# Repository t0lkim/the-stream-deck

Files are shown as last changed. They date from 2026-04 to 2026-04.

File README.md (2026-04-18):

# TheStreamDeck

A Raspberry Pi-based unified streaming audio appliance. One device, one amp input, instant source switching, album art on screen, and physical analogue VU meters.

## Sources

- Tidal HiFi Plus
- Plexamp (local library)
- BBC 6 Music
- Internet radio

## Features

- Touchscreen display with album artwork and transport controls
- Physical analogue VU meters showing real-time audio levels
- Instant source switching — tap to change from Tidal to BBC radio without touching the amplifier
- Single amp input eliminates multi-device cable management

## Platform

Raspberry Pi

## License

MIT

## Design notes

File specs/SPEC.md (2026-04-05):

# TheStreamDeck — Unified Streaming Audio Appliance

**Version:** 0.2.0 (Design Spec)  
**Author:** Mike & Maia  
**Date:** 2026-04-04  
**Status:** Draft  

---

## 1. Overview

A Raspberry Pi 4-based appliance that consolidates BBC 6 Music, Tidal HiFi Plus, Plexamp, and internet radio into a single device with a 13.3" touchscreen, physical source-selection buttons, real-time VU meter visualisation, and S/PDIF digital output to a NAD C 3xx integrated amplifier.

One device. One amp input. Instant switching. Album art on screen.

---

## 2. Hardware Architecture

### 2.1 Core Components

| Component | Selection | Rationale |
|---|---|---|
| **SBC** | Raspberry Pi 4 Model B (4GB) | Already owned. Quad A72 @ 1.5GHz, VideoCore VI GPU. |
| **Transport HAT** | HiFiBerry Digi2 Pro | S/PDIF output (optical + coax), dual oscillator for low jitter, 192kHz/24-bit. NOT a DAC — pure digital transport. |
| **Display** | Waveshare 13.3" HDMI LCD (H) V2 with Case | 1920x1080 IPS, HDMI + USB touch (no GPIO conflict), 10-point capacitive, toughened glass, built-in speaker, tilt stand. ~$160-190. |
| **Amplifier** | NAD C 3xx (existing) | Optical digital input, Cirrus Logic internal DAC. Handles all D/A conversion. |
| **VU Meter DAC** | MCP4922 (DIP-16) | Dual 12-bit SPI DAC. Drives L/R analogue panel meters. Zero jitter, 4096 steps. SPI0 (GPIO 8/10/11) — no HiFiBerry conflict. ~$3-4. |
| **VU Panel Meters** | 2x 85mm analogue VU meters with backlight | Moving-coil needle meters, 200uA FSD. Driven by MCP4922 via series resistor (15k + 5k trim pot per channel). ~$8-40/pair depending on quality tier. |
| **Storage** | 64GB A2 microSD | Fast random I/O for OS + applications. |
| **Network** | Ethernet (wired) | Reliability for streaming. Wi-Fi available as fallback. |

### 2.2 Audio Signal Path

```
Streaming Source (Tidal / Plexamp / MPD)
    |
    v
PipeWire (audio server / multiplexer)
    |
    +---> HiFiBerry Digi2 Pro (I2S → S/PDIF framing)
    |         |
    |         +---> TOSLINK optical cable
    |                   |
    |                   v
    |              NAD C 3xx optical input
    |                   |
    |                   v
    |              NAD internal DAC (Cirrus Logic, D/A conversion)
    |                   |
    |                   v
    |              NAD amplifier stage → Speakers
    |
    +---> PipeWire monitor source (audio tap for visualisation)
              |
              v
         VU Meter / Spectrum Analyser (cpal + RustFFT → display)
```

**Why Digi HAT, not DAC HAT:**
- The Pi stays purely digital — zero analogue stages on the Pi side
- The NAD's Cirrus Logic DAC is purpose-built with dedicated power regulation and shielding — objectively superior to any ~$30 Pi HAT DAC
- Using a DAC HAT to feed the NAD's analogue input = unnecessary double conversion (digital → HAT DAC → analogue → NAD → amp)
- TOSLINK optical provides galvanic isolation, eliminating ground loop hum from the Pi's switching PSU
- Full 24-bit/192kHz support end-to-end

### 2.3 Physical Controls

Source switching buttons connected via GPIO (pins not used by Digi HAT — HDMI display uses no GPIO):

| Button | Function | GPIO Pin (suggested) |
|---|---|---|
| 1 | BBC 6 Music | GPIO 17 |
| 2 | Tidal | GPIO 27 |
| 3 | Plexamp | GPIO 22 |
| 4 | Radio (cycle presets) | GPIO 23 |
| 5 | Play/Pause | GPIO 24 |
| 6 | Volume +/- (rotary encoder) | GPIO 5/6 |

The touchscreen also provides full source selection and transport controls.

### 2.4 GPIO Pin Allocation

| Pin Range | Used By |
|---|---|
| GPIO 18, 19, 20, 21 | HiFiBerry Digi2 Pro (I2S: BCK, LRCK, DIN, DOUT) |
| GPIO 4 | HiFiBerry Digi2 Pro (clock select) |
| GPIO 8 (SPI0 CE0) | MCP4922 DAC chip select |
| GPIO 10 (SPI0 MOSI) | MCP4922 DAC data in |
| GPIO 11 (SPI0 SCLK) | MCP4922 DAC clock |
| GPIO 2-3 (I2C) | Available |
| GPIO 17, 22-24, 27 | Physical buttons |
| GPIO 5, 6 | Rotary encoder (volume) |

Display connects via HDMI (video) + USB (touch) — zero GPIO usage. No conflicts between display, Digi HAT, DAC, and buttons.

### 2.5 Analogue VU Meter Subsystem

Physical needle VU meters driven digitally from the audio analysis pipeline via SPI DAC.

**Signal chain:**
```
PipeWire monitor tap → RMS per channel (Rust)
    → VU ballistics filter (300ms IIR)
    → MCP4922 SPI write (12-bit, dual channel)
    → Series resistor (15k + 5k trim pot)
    → 85mm analogue panel meter (200uA FSD)
```

**Wiring:**
```
Pi 3.3V ──── MCP4922 VDD, VRefA, VRefB, SHDN
Pi GND  ──── MCP4922 VSS, LDAC
Pi GPIO8 ─── MCP4922 CS
Pi GPIO10 ── MCP4922 SDI
Pi GPIO11 ── MCP4922 SCK

MCP4922 VOutA ──[15k + 5k trim]── VU Left+  ── VU Left-  ── GND
MCP4922 VOutB ──[15k + 5k trim]── VU Right+ ── VU Right- ── GND
```

**Why not PWM?** Hardware PWM on GPIO 18 conflicts with HiFiBerry PCM_CLK. Software PWM produces visible needle jitter (~13 usable steps). The MCP4922 gives 4096 steps with zero jitter — proven superior in head-to-head testing (Hackaday.io reference project).

**Power:** Both meters draw ~0.4mA total from the Pi's 3.3V rail. Negligible.

**Ballistics:** Implement a VU-standard IIR filter in software (300ms time constant, 1-1.5% overshoot). Cheap meters need software damping due to poor mechanical damping. Quality meters (Flash Star, Hoyt) can rely on their own mechanical inertia with only a gentle 50ms software smoothing pass.

**Meter quality tiers:**

| Tier | Source | Price/pair | Damping | Notes |
|---|---|---|---|---|
| Budget | AliExpress "85mm VU meter" | $8-15 | Poor — needs software compensation | Adequate for decorative/indicative use |
| Mid-range | Flash Star / Sifam | $30-40 each | Good — proper VU behaviour | Recommended for this build |
| Professional | Hoyt AL19R/AL20 | $50-150 each | Excellent — ANSI-standard | Buy-once quality |

---

## 3. Software Architecture

### 3.1 OS Layer

| Component | Choice | Notes |
|---|---|---|
| **OS** | Raspberry Pi OS Lite 64-bit (Bookworm) | Minimal, ARM64, PipeWire default |
| **Audio Server** | PipeWire | Default on Bookworm. Multiplexes all sources. Monitor sources for visualisation. |
| **Container Runtime** | Podman (rootless) | For Tidal Connect. No Docker daemon. |
| **Init** | systemd | User services for Plexamp, system services for MPD |

### 3.2 Audio Sources

#### BBC 6 Music (and other BBC/internet radio)
- **Player:** MPD (Music Player Daemon)
- **Protocol:** HLS (AAC-LC)
- **Quality:** 320kbps AAC (UK), 96kbps (worldwide)
- **Stream URL:** `http://lstn.lv/bbc.m3u8?station=bbc_6music&bitrate=320000`
- **Config:** MPD playlist entries for each station
- **Switching:** MPD client commands (`mpc play`, `mpc stop`)
- **Metadata:** MPD provides ICY metadata (artist/title) from stream

#### Tidal HiFi Plus
- **Player:** GioF71/tidal-connect (Podman container)
- **Protocol:** Tidal Connect (proprietary, runs inside container)
- **Quality:** Lossless FLAC (16/44.1 or 24/96 depending on source)
- **Auth:** OAuth via Tidal mobile app (cast to this device)
- **Control model:** Cast-based — control from Tidal app on phone/tablet, Pi is the renderer
- **Metadata API:** OpenTidal (TypeScript) or rstidal (Rust) for album art, track info
- **Container config:**
  ```bash
  podman run -d --name tidal-connect \
    --device /dev/snd \
    -e FRIENDLY_NAME="StreamDeck" \
    -e FORCE_PLAYER_BACKEND="PipeWire" \
    giof71/tidal-connect:latest
  ```

#### Plexamp (Local Plex Library)
- **Player:** Plexamp headless (Node.js 20)
- **Requirement:** Plex Pass (mandatory)
- **Setup:** systemd user service via odinb/bash-plexamp-installer
- **Control model:** Cast-based — control from any Plexamp client on network
- **Web UI:** `http://localhost:32500` — can display in Chromium kiosk on touchscreen
- **Quality:** Depends on Plex library encoding (FLAC preferred)
- **Metadata:** Plex API provides full album art, artist info, lyrics

#### Internet Radio (Generic)
- **Player:** MPD
- **Protocol:** HLS, Shoutcast/Icecast (varies per station)
- **Config:** MPD playlist with station URLs
- **Presets:** Configurable list of favourite stations

### 3.3 Source Switching Architecture

```
                    ┌─────────────────────┐
                    │   Source Controller  │
                    │   (Rust daemon)      │
                    └─────────┬───────────┘
                              │
              ┌───────────────┼───────────────┐
              │               │               │
              v               v               v
        ┌──────────┐   ┌──────────┐   ┌──────────┐
        │   MPD    │   │  Tidal   │   │ Plexamp  │
        │ (radio)  │   │ Connect  │   │(headless)│
        └────┬─────┘   └────┬─────┘   └────┬─��───┘
             │               │               │
             └───────────────┼───────────────┘
                             │
                             v
                    ┌─────────────────────┐
                    │     PipeWire        │
                    │  (session manager)  │
                    └─────────┬───────────┘
                              │
                    ┌─────────┴─────────┐
                    │                   │
                    v                   v
           ┌──────────────┐   ┌──────────────┐
           │ Digi2 Pro    │   │ Monitor Src  │
           │ (S/PDIF out) │   │ (VU meter)   │
           └──────────────┘   └──────────────┘
```

**Source Controller** is a custom Rust daemon that:
1. Listens for GPIO button presses and touchscreen source-select events
2. Mutes/stops the current source (e.g., `mpc stop` for MPD)
3. Activates the new source
4. Updates the UI to reflect active source
5. PipeWire handles audio routing — no manual ALSA device management

**Switching latency target:** < 3 seconds from button press to audio output.

### 3.4 Display & UI

#### Layout (1920x1080, landscape — Waveshare 13.3")

```
┌──────────────────────────────────────────────────────────────────────────┐
│                                                                          │
│  ┌───────────────────────────┐  ┌──────────────────────────────────────┐ │
│  │                           │  │                                      │ │
│  │      Album Artwork        │  │        VU Meter / Spectrum           │ │
│  │       (600x600)           │  │         Visualisation                │ │
│  │                           │  │          (L + R)                     │ │
│  │                           │  │                                      │ │
│  │                           │  │                                      │ │
│  └───────────────────────────┘  └──────────────────────────────────────┘ │
│                                                                          │
│  ┌──────────────────────────────────────────────────────────────────────┐ │
│  │  Track: Song Title                                    Artist Name   │ │
│  │  Album: Album Title                                   FLAC 24/96   │ │
│  └──────────────────────────────────────────────────────────────────────┘ │
│                                                                          │
│  ┌──────┐ ┌──────┐ ┌──────┐ ┌──────┐    ┌────┐ ┌────────────┐ ┌────┐  │
│  │ BBC  │ │ TDAL │ │ PLEX │ │ RDIO │    │ ◀◀ │ │   ▶ / ⏸   │ │ ▶▶ │  │
│  └──────┘ └──────┘ └──────┘ └──────┘    └────┘ └────────────┘ └────┘  │
│                                                                          │
└──────────────────────────────────────────────────────────────────────────┘
```

- **Album art:** Prominent, high-resolution (600x600px display area — 1080p gives room to breathe)
- **VU meter:** Real-time L/R needle-style or bar-style, user-switchable to spectrum analyser. Full HD canvas for detailed needle rendering.
- **Now playing:** Track title, artist, album, format/bitrate — larger text at 1080p
- **Source buttons:** Touch targets for source switching (mirror physical buttons)
- **Transport:** Play/pause, skip (where applicable)

#### UI Technology Options

| Option | Stack | Pros | Cons |
|---|---|---|---|
| **A. Rust + wgpu** | Native framebuffer, GPU-accelerated | Fastest, lowest overhead, single language with audio engine | Most dev effort, custom widget toolkit |
| **B. Rust + Slint** | Native UI toolkit for embedded | Declarative UI, GPU-accelerated, designed for embedded touchscreens | Newer ecosystem, licensing (free for open source) |
| **C. TypeScript + Electron** | Chromium-based | Rapid development, web tech, rich ecosystem | Higher memory/CPU overhead (~200MB RAM) |
| **D. Chromium kiosk + web app** | Lightweight web app | Simplest for Plexamp web UI integration | Limited VU meter performance |

**Recommended: Option B (Rust + Slint)** — Purpose-built for embedded touchscreen UIs, GPU-accelerated, works with framebuffer (no X11/Wayland needed), and keeps the entire codebase in Rust. The VU meter can render at 60fps via Slint's OpenGL ES backend on VideoCore VI.

### 3.5 VU Meter & Visualisation

**Audio Analysis Pipeline:**
```
PipeWire monitor source
    │
    v
cpal (Rust) — captures audio frames from monitor
    │
    v
RustFFT (1024-point, NEON-accelerated on aarch64)
    │
    ├── RMS per channel → VU ballistics IIR filter (300ms)
    │       │
    │       ├── MCP4922 SPI write → Physical analogue VU meters (L/R)
    │       │
    │       └── Slint VU widget → On-screen VU visualisation
    │
    └── FFT bins → Spectrum analyser (optional view)
    │
    v
Slint UI renderer → HDMI Display @ 60fps
```

**Performance budget (Pi 4):**

| Component | CPU | Latency |
|---|-----|---|
| PipeWire monitor tap | <0.5% | ~5ms |
| 1024-point FFT (RustFFT + NEON) | <0.5% | ~23ms (window) |
| VU ballistics + MCP4922 SPI write | <0.1% | ~1ms |
| 1080p 60fps render (OpenGL ES) | ~8-15% | <16ms |
| **Total** | **~9-16%** | **~44ms** |

84-91% CPU remains for audio playback. 44ms visual latency is imperceptible for VU meters. 1080p rendering costs slightly more GPU than 720p but Pi 4's VideoCore VI handles it comfortably.

**VU Meter Modes (user-switchable via touch):**
1. **Classic VU:** Dual analogue needle meters (L/R), ballistic response matching real VU meter standards (300ms integration, 1% overshoot)
2. **LED Bar:** Horizontal or vertical LED-style bars (L/R), peak hold with decay
3. **Spectrum:** Frequency spectrum analyser, 32 or 64 bands

### 3.6 Volume Control

| Strategy | Method | Notes |
|---|---|---|
| **Software (PipeWire)** | PipeWire volume control via `wpctl` | Simple, works for all sources. Minor quality loss at very low volumes (bit depth reduction). |
| **Pass-through** | No Pi volume control, use NAD remote | Cleanest signal path. Requires NAD remote or amp panel. |

**Recommended:** Software volume via PipeWire as default, with an option to disable for pass-through mode. The rotary encoder on GPIO 5/6 controls PipeWire master volume.

---

## 4. Build Phases

### Phase 1: Bare Metal Audio (Week 1-2)
- Flash Pi OS Lite 64-bit
- Install and configure HiFiBerry Digi2 Pro
- Verify S/PDIF output to NAD via TOSLINK
- Configure PipeWire
- Install MPD, add BBC 6 Music stream, verify playback
- Install Plexamp headless, verify playback
- Install Tidal Connect (Podman), verify playback
- Verify source switching works (manual CLI commands)

### Phase 2: Source Controller Daemon (Week 3)
- Rust daemon: GPIO button listener
- Source state machine (stop current, start new)
- PipeWire integration for audio routing
- CLI interface for testing
- Verify < 3 second switching

### Phase 3: Display & UI (Week 4-5)
- Connect Waveshare 13.3" HDMI LCD (H) V2 (HDMI + USB touch)
- Slint UI: source selection, now-playing display (1920x1080)
- Album art retrieval (Plex API, OpenTidal API, MPD ICY metadata)
- Touch input handling (source buttons, transport controls)

### Phase 4: VU Meter (Week 6)
- cpal audio capture from PipeWire monitor
- RustFFT analysis pipeline
- Slint VU meter widget (classic needle + LED bar modes)
- Spectrum analyser mode
- 60fps render validation

### Phase 5: Enclosure & Polish (Week 7-8)
- Physical enclosure design (Pi mounts behind 13.3" display via VESA/bracket, button panel alongside)
- Button panel integration
- Boot-to-UI (systemd auto-start, no desktop environment)
- Error handling (network loss, service crashes, auto-restart)
- Final integration testing

---

## 5. Bill of Materials

| Item | Estimated Cost | Status |
|---|---|---|
| Raspberry Pi 4 Model B (4GB) | -- | Already owned |
| HiFiBerry Digi2 Pro | ~$35 | To purchase |
| Waveshare 13.3" HDMI LCD (H) V2 with Case | ~$175 | To purchase |
| TOSLINK optical cable (1-2m) | ~$8 | To purchase |
| 64GB A2 microSD | ~$10 | Likely owned |
| Tactile buttons (6x) + rotary encoder | ~$10 | To purchase |
| Stacking GPIO header (for button access) | ~$3 | To purchase |
| MCP4922 dual SPI DAC (DIP-16) | ~$4 | To purchase |
| 2x 85mm analogue VU panel meters + backlight | ~$15-40 | To purchase (tier dependent) |
| 2x 15k resistor + 2x 5k trim pot + 100nF cap | ~$2 | To purchase |
| Enclosure / mounting bracket | ~$15-30 | To design/purchase |
| **Total (excl. owned items)** | **~$275-335** | |

---

## 6. Risks & Mitigations

| Risk | Severity | Mitigation |
|---|---|---|
| Tidal kills unofficial Connect protocol | High | Fall back to Tidal via phone cast (UPnP/DLNA). Monitor GioF71 repo for updates. |
| Plexamp headless drops ARM64 support | Low | Plex is invested in Pi ecosystem. Worst case: MPD + Plex DLNA. |
| BBC changes stream URLs/format | Low | Community-maintained URL lists. MPD handles format changes. |
| PipeWire source switching causes audio pops | Medium | Implement soft mute (fade out 50ms → switch → fade in 50ms) in source controller. |
| Slint licensing changes | Low | Open source use is free. Fallback: wgpu + custom widgets. |
| Pi 4 thermal throttling during sustained VU + playback | Low | Passive heatsink case. VU analysis is <16% CPU — well within thermal budget. |
| Cheap VU meter overshoot/ringing | Medium | Software VU ballistics filter (300ms IIR) compensates for poor mechanical damping. Use 400-500ms tau for budget meters. |

---

## 7. Future Enhancements (Out of Scope)

- AirPlay 2 support (shairport-sync)
- Spotify Connect
- Bluetooth receiver mode
- Room correction DSP (CamillaDSP)
- Remote web UI for control from phone/laptop
- Multiple DAC/amp output support
- IR remote control integration

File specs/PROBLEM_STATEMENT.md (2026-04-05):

# Problem Statement: Streaming Audio Appliance

**Problem Statement:**
An audiophile with multiple streaming subscriptions (Tidal HiFi Plus, Plexamp/Plex, BBC 6 Music, internet radio) experiences frustrating, slow source switching when listening through a NAD C 3xx integrated amplifier, because each service runs on a different device requiring manual amp input selection. This fragmented workflow disrupts listening sessions, adds unnecessary physical interaction, and prevents enjoying visual elements like album artwork during playback.

**Components:**
- **Stakeholder:** Home audiophile with NAD pre/power amp, multiple streaming subscriptions, and Raspberry Pi 4 hardware
- **Problem:** Switching between audio sources requires changing physical devices and amp inputs — slow, disruptive, and frustrating
- **Context:** Daily listening sessions across BBC 6 Music, Tidal, Plexamp (local library), and internet radio stations
- **Impact:** Broken listening flow, reluctance to switch sources, underuse of paid subscriptions, no visual engagement (album art, now-playing info)
- **Constraints:**
  - Must use existing Raspberry Pi 4 Model B
  - Must connect to NAD C 3xx via single input (digital optical preferred)
  - PiOS as operating system
  - No Python in implementation stack (Rust/TypeScript preferred)
  - No cloud dependencies for core playback
  - Plex Pass required for Plexamp (already owned)
  - Tidal HiFi Plus subscription (already owned)
  - BBC 320kbps streams geo-restricted to UK
- **Measurable:**
  - Source switching completes in under 3 seconds
  - All four sources (BBC 6 Music, Tidal, Plexamp, internet radio) playable from one device
  - Single amp input used for all sources
  - Album artwork displayed during playback
  - VU meter visualisation responds accurately to L/R audio channels
  - Zero audible pops or clicks during source transitions

**First Principles Check:**
- **Root Problem:** CONFIRMED — the root issue is multiple independent audio devices competing for a single listening position. The amp's input selector is a symptom of the real problem: no unified audio transport layer.
- **Key Assumptions:**
  - Tidal Connect (unofficial Docker) will remain functional (risk: Tidal could break it)
  - PipeWire can multiplex all sources without audible degradation
  - Pi 4 has sufficient CPU for simultaneous playback + VU meter rendering
  - The NAD's internal DAC is superior to any Pi HAT DAC (validated by spec analysis)
- **Constraints Status:**
  - Pi 4 hardware: verified immutable (owned)
  - NAD amp: verified immutable (owned, has optical digital input)
  - No Python: negotiable but strongly preferred
  - Plex Pass: verified immutable (Plexamp requirement)

**Priority:** High — daily quality-of-life improvement
**Status:** Active
**Created:** 2026-04-04

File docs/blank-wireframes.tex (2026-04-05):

\documentclass{article}
\usepackage[a3paper,landscape,margin=8mm]{geometry}
\usepackage{tikz}
\usepackage{fontspec}
\setmainfont{Inter}
\pagestyle{empty}

\begin{document}

%% ============================================================
%% PAGE 1: 435 x 70mm blank wireframe (92% scale)
%% ============================================================

\noindent
\begin{center}
{\fontsize{13}{16}\selectfont\bfseries TheStreamDeck -- Blank Wireframe (70mm)}\\[1pt]
{\fontsize{8}{10}\selectfont\color{gray} 92\% scale on A3 (actual: 435 x 70mm). Clean real estate for free sketching.}
\end{center}
\vspace{8mm}

\begin{center}
\begin{tikzpicture}[x=0.92mm, y=0.92mm]
  \def\cw{435} \def\ch{70}

  % Light grid (10mm)
  \begin{scope}
    \clip[rounded corners=1.8mm] (0,0) rectangle (\cw,\ch);
    \foreach \x in {0,10,...,435} { \draw[gray!12, line width=0.15pt] (\x,0) -- (\x,\ch); }
    \foreach \y in {0,10,...,70} { \draw[gray!12, line width=0.15pt] (0,\y) -- (\cw,\y); }
  \end{scope}

  % Case outline
  \draw[black, line width=0.5pt, rounded corners=1.8mm] (0,0) rectangle (\cw,\ch);

  % Centre crosshair (very subtle)
  \draw[gray!15, line width=0.3pt, dashed] (\cw/2,0) -- (\cw/2,\ch);
  \draw[gray!15, line width=0.3pt, dashed] (0,\ch/2) -- (\cw,\ch/2);

  % Feet
  \fill[gray!20, rounded corners=1mm] (20,-6) rectangle (40,0);
  \fill[gray!20, rounded corners=1mm] (\cw-40,-6) rectangle (\cw-20,0);

  % Dimensions
  \draw[gray!30, line width=0.2pt, <->] (0,\ch+6) -- (\cw,\ch+6);
  \node[font=\fontsize{6}{8}\selectfont, text=gray!35] at (\cw/2,\ch+10) {435mm};
  \draw[gray!30, line width=0.2pt, <->] (\cw+6,0) -- (\cw+6,\ch);
  \node[font=\fontsize{6}{8}\selectfont, text=gray!35, rotate=90] at (\cw+10,\ch/2) {70mm};
\end{tikzpicture}
\end{center}

\vspace{12mm}

% Second copy for another sketch
\begin{center}
\begin{tikzpicture}[x=0.92mm, y=0.92mm]
  \def\cw{435} \def\ch{70}
  \begin{scope}
    \clip[rounded corners=1.8mm] (0,0) rectangle (\cw,\ch);
    \foreach \x in {0,10,...,435} { \draw[gray!12, line width=0.15pt] (\x,0) -- (\x,\ch); }
    \foreach \y in {0,10,...,70} { \draw[gray!12, line width=0.15pt] (0,\y) -- (\cw,\y); }
  \end{scope}
  \draw[black, line width=0.5pt, rounded corners=1.8mm] (0,0) rectangle (\cw,\ch);
  \draw[gray!15, line width=0.3pt, dashed] (\cw/2,0) -- (\cw/2,\ch);
  \draw[gray!15, line width=0.3pt, dashed] (0,\ch/2) -- (\cw,\ch/2);
  \fill[gray!20, rounded corners=1mm] (20,-6) rectangle (40,0);
  \fill[gray!20, rounded corners=1mm] (\cw-40,-6) rectangle (\cw-20,0);
  \draw[gray!30, line width=0.2pt, <->] (0,\ch+6) -- (\cw,\ch+6);
  \node[font=\fontsize{6}{8}\selectfont, text=gray!35] at (\cw/2,\ch+10) {435mm};
  \draw[gray!30, line width=0.2pt, <->] (\cw+6,0) -- (\cw+6,\ch);
  \node[font=\fontsize{6}{8}\selectfont, text=gray!35, rotate=90] at (\cw+10,\ch/2) {70mm};
\end{tikzpicture}
\end{center}

\vspace{12mm}

% Third copy
\begin{center}
\begin{tikzpicture}[x=0.92mm, y=0.92mm]
  \def\cw{435} \def\ch{70}
  \begin{scope}
    \clip[rounded corners=1.8mm] (0,0) rectangle (\cw,\ch);
    \foreach \x in {0,10,...,435} { \draw[gray!12, line width=0.15pt] (\x,0) -- (\x,\ch); }
    \foreach \y in {0,10,...,70} { \draw[gray!12, line width=0.15pt] (0,\y) -- (\cw,\y); }
  \end{scope}
  \draw[black, line width=0.5pt, rounded corners=1.8mm] (0,0) rectangle (\cw,\ch);
  \draw[gray!15, line width=0.3pt, dashed] (\cw/2,0) -- (\cw/2,\ch);
  \draw[gray!15, line width=0.3pt, dashed] (0,\ch/2) -- (\cw,\ch/2);
  \fill[gray!20, rounded corners=1mm] (20,-6) rectangle (40,0);
  \fill[gray!20, rounded corners=1mm] (\cw-40,-6) rectangle (\cw-20,0);
  \draw[gray!30, line width=0.2pt, <->] (0,\ch+6) -- (\cw,\ch+6);
  \node[font=\fontsize{6}{8}\selectfont, text=gray!35] at (\cw/2,\ch+10) {435mm};
  \draw[gray!30, line width=0.2pt, <->] (\cw+6,0) -- (\cw+6,\ch);
  \node[font=\fontsize{6}{8}\selectfont, text=gray!35, rotate=90] at (\cw+10,\ch/2) {70mm};
\end{tikzpicture}
\end{center}

\newpage

%% ============================================================
%% PAGE 2: 435 x 102mm blank wireframe (92% scale)
%% ============================================================

\noindent
\begin{center}
{\fontsize{13}{16}\selectfont\bfseries TheStreamDeck -- Blank Wireframe (102mm)}\\[1pt]
{\fontsize{8}{10}\selectfont\color{gray} 92\% scale on A3 (actual: 435 x 102mm). Clean real estate for free sketching.}
\end{center}
\vspace{8mm}

\begin{center}
\begin{tikzpicture}[x=0.92mm, y=0.92mm]
  \def\cw{435} \def\ch{102}
  \begin{scope}
    \clip[rounded corners=1.8mm] (0,0) rectangle (\cw,\ch);
    \foreach \x in {0,10,...,435} { \draw[gray!12, line width=0.15pt] (\x,0) -- (\x,\ch); }
    \foreach \y in {0,10,...,110} { \draw[gray!12, line width=0.15pt] (0,\y) -- (\cw,\y); }
  \end{scope}
  \draw[black, line width=0.5pt, rounded corners=1.8mm] (0,0) rectangle (\cw,\ch);
  \draw[gray!15, line width=0.3pt, dashed] (\cw/2,0) -- (\cw/2,\ch);
  \draw[gray!15, line width=0.3pt, dashed] (0,\ch/2) -- (\cw,\ch/2);
  \fill[gray!20, rounded corners=1mm] (20,-6) rectangle (40,0);
  \fill[gray!20, rounded corners=1mm] (\cw-40,-6) rectangle (\cw-20,0);
  \draw[gray!30, line width=0.2pt, <->] (0,\ch+6) -- (\cw,\ch+6);
  \node[font=\fontsize{6}{8}\selectfont, text=gray!35] at (\cw/2,\ch+10) {435mm};
  \draw[gray!30, line width=0.2pt, <->] (\cw+6,0) -- (\cw+6,\ch);
  \node[font=\fontsize{6}{8}\selectfont, text=gray!35, rotate=90] at (\cw+10,\ch/2) {102mm};
\end{tikzpicture}
\end{center}

\vspace{12mm}

% Second copy
\begin{center}
\begin{tikzpicture}[x=0.92mm, y=0.92mm]
  \def\cw{435} \def\ch{102}
  \begin{scope}
    \clip[rounded corners=1.8mm] (0,0) rectangle (\cw,\ch);
    \foreach \x in {0,10,...,435} { \draw[gray!12, line width=0.15pt] (\x,0) -- (\x,\ch); }
    \foreach \y in {0,10,...,110} { \draw[gray!12, line width=0.15pt] (0,\y) -- (\cw,\y); }
  \end{scope}
  \draw[black, line width=0.5pt, rounded corners=1.8mm] (0,0) rectangle (\cw,\ch);
  \draw[gray!15, line width=0.3pt, dashed] (\cw/2,0) -- (\cw/2,\ch);
  \draw[gray!15, line width=0.3pt, dashed] (0,\ch/2) -- (\cw,\ch/2);
  \fill[gray!20, rounded corners=1mm] (20,-6) rectangle (40,0);
  \fill[gray!20, rounded corners=1mm] (\cw-40,-6) rectangle (\cw-20,0);
  \draw[gray!30, line width=0.2pt, <->] (0,\ch+6) -- (\cw,\ch+6);
  \node[font=\fontsize{6}{8}\selectfont, text=gray!35] at (\cw/2,\ch+10) {435mm};
  \draw[gray!30, line width=0.2pt, <->] (\cw+6,0) -- (\cw+6,\ch);
  \node[font=\fontsize{6}{8}\selectfont, text=gray!35, rotate=90] at (\cw+10,\ch/2) {102mm};
\end{tikzpicture}
\end{center}

\end{document}

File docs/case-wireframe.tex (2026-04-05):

\documentclass{article}
\usepackage[a3paper,landscape,margin=8mm]{geometry}
\usepackage{tikz}
\usepackage{fontspec}
\setmainfont{Inter}
\pagestyle{empty}

\begin{document}
\noindent
\begin{center}
{\fontsize{13}{16}\selectfont\bfseries TheStreamDeck -- Front Panel Wireframes (70mm height)}\\[1pt]
{\fontsize{8}{10}\selectfont\color{gray} 92\% scale on A3 (actual case is 435 x 70mm). Multiply measurements by 1.087 for true dimensions.}
\end{center}
\vspace{2mm}

%% Scale: 0.92mm per mm (fits 435mm case on A3 landscape with 8mm margins)

%% ============================================================
%% OPTION A: Circular VU 45mm + 5" display + buttons + rotary
%% ============================================================

\noindent
{\fontsize{9}{11}\selectfont\bfseries A: 45mm circular VU + 5" display + 4 buttons + rotary}

\vspace{1mm}

\begin{center}
\begin{tikzpicture}[x=0.92mm, y=0.92mm]
  \def\cw{435} \def\ch{70}

  \begin{scope}
    \clip[rounded corners=1.8mm] (0,0) rectangle (\cw,\ch);
    \foreach \x in {0,10,...,435} { \draw[gray!15, line width=0.15pt] (\x,0) -- (\x,\ch); }
    \foreach \y in {0,10,...,70} { \draw[gray!15, line width=0.15pt] (0,\y) -- (\cw,\y); }
  \end{scope}
  \draw[black, line width=0.5pt, rounded corners=1.8mm] (0,0) rectangle (\cw,\ch);
  \fill[gray!20, rounded corners=0.9mm] (20,-6) rectangle (40,0);
  \fill[gray!20, rounded corners=0.9mm] (\cw-40,-6) rectangle (\cw-20,0);

  % VU L: 45mm circular
  \draw[gray!45, line width=0.4pt, dashed] (35,35) circle (22.5);
  \node[font=\fontsize{6}{8}\selectfont, text=gray!50] at (35,37) {VU L};
  \node[font=\fontsize{4}{5}\selectfont, text=gray!35] at (35,28) {45mm};

  % VU R: 45mm circular
  \draw[gray!45, line width=0.4pt, dashed] (330,35) circle (22.5);
  \node[font=\fontsize{6}{8}\selectfont, text=gray!50] at (330,37) {VU R};
  \node[font=\fontsize{4}{5}\selectfont, text=gray!35] at (330,28) {45mm};

  % 5" Display: 111 x 62mm centred between VUs
  \draw[black!55, line width=0.5pt, dashed] (127,4) rectangle (238,66);
  \node[font=\fontsize{7}{9}\selectfont, text=gray!45] at (182.5,39) {5" Display};
  \node[font=\fontsize{5}{7}\selectfont, text=gray!35] at (182.5,28) {111 x 62mm};
  \draw[gray!12, line width=0.2pt, dashed] (182.5,4) -- (182.5,66);
  \draw[gray!12, line width=0.2pt, dashed] (127,35) -- (238,35);

  % 4 buttons
  \foreach \i/\lbl in {1/BBC,2/TDL,3/PLX,4/RDO} {
    \pgfmathsetmacro{\bty}{70 - \i * 15 - 2}
    \draw[gray!40, line width=0.3pt, dashed] (390,\bty) circle (5);
    \node[font=\fontsize{3.5}{4}\selectfont, text=gray!40] at (390,\bty) {\lbl};
  }
  % Rotary
  \draw[gray!40, line width=0.3pt, dashed] (420,35) circle (8);
  \node[font=\fontsize{4}{5}\selectfont, text=gray!40] at (420,35) {VOL};

  % Dims
  \draw[gray!35, line width=0.2pt, <->] (0,\ch+4) -- (\cw,\ch+4);
  \node[font=\fontsize{5}{7}\selectfont, text=gray!40] at (\cw/2,\ch+8) {435mm};
  \draw[gray!35, line width=0.2pt, <->] (\cw+4,0) -- (\cw+4,\ch);
  \node[font=\fontsize{5}{7}\selectfont, text=gray!40, rotate=90] at (\cw+8,\ch/2) {70mm};
\end{tikzpicture}
\end{center}

\vspace{4mm}

%% ============================================================
%% OPTION B: Circular VU 50mm + 5" display + rotary only
%% ============================================================

\noindent
{\fontsize{9}{11}\selectfont\bfseries B: 50mm circular VU + 5" display + rotary only}

\vspace{1mm}

\begin{center}
\begin{tikzpicture}[x=0.92mm, y=0.92mm]
  \def\cw{435} \def\ch{70}

  \begin{scope}
    \clip[rounded corners=1.8mm] (0,0) rectangle (\cw,\ch);
    \foreach \x in {0,10,...,435} { \draw[gray!15, line width=0.15pt] (\x,0) -- (\x,\ch); }
    \foreach \y in {0,10,...,70} { \draw[gray!15, line width=0.15pt] (0,\y) -- (\cw,\y); }
  \end{scope}
  \draw[black, line width=0.5pt, rounded corners=1.8mm] (0,0) rectangle (\cw,\ch);
  \fill[gray!20, rounded corners=0.9mm] (20,-6) rectangle (40,0);
  \fill[gray!20, rounded corners=0.9mm] (\cw-40,-6) rectangle (\cw-20,0);

  % VU L: 50mm circular
  \draw[gray!45, line width=0.4pt, dashed] (40,35) circle (25);
  \node[font=\fontsize{6}{8}\selectfont, text=gray!50] at (40,37) {VU L};
  \node[font=\fontsize{4}{5}\selectfont, text=gray!35] at (40,27) {50mm};

  % VU R: 50mm circular
  \draw[gray!45, line width=0.4pt, dashed] (395,35) circle (25);
  \node[font=\fontsize{6}{8}\selectfont, text=gray!50] at (395,37) {VU R};
  \node[font=\fontsize{4}{5}\selectfont, text=gray!35] at (395,27) {50mm};

  % 5" Display centred
  \draw[black!55, line width=0.5pt, dashed] (162,4) rectangle (273,66);
  \node[font=\fontsize{7}{9}\selectfont, text=gray!45] at (217.5,39) {5" Display};
  \node[font=\fontsize{5}{7}\selectfont, text=gray!35] at (217.5,28) {111 x 62mm};
  \draw[gray!12, line width=0.2pt, dashed] (217.5,4) -- (217.5,66);
  \draw[gray!12, line width=0.2pt, dashed] (162,35) -- (273,35);

  % Dims
  \draw[gray!35, line width=0.2pt, <->] (0,\ch+4) -- (\cw,\ch+4);
  \node[font=\fontsize{5}{7}\selectfont, text=gray!40] at (\cw/2,\ch+8) {435mm};
  \draw[gray!35, line width=0.2pt, <->] (\cw+4,0) -- (\cw+4,\ch);
  \node[font=\fontsize{5}{7}\selectfont, text=gray!40, rotate=90] at (\cw+8,\ch/2) {70mm};
\end{tikzpicture}
\end{center}

\vspace{4mm}

%% ============================================================
%% OPTION C: Rectangular VU 60x40mm (landscape) + 5" display + rotary
%% ============================================================

\noindent
{\fontsize{9}{11}\selectfont\bfseries C: 60x40mm rectangular VU (landscape) + 5" display + rotary}

\vspace{1mm}

\begin{center}
\begin{tikzpicture}[x=0.92mm, y=0.92mm]
  \def\cw{435} \def\ch{70}

  \begin{scope}
    \clip[rounded corners=1.8mm] (0,0) rectangle (\cw,\ch);
    \foreach \x in {0,10,...,435} { \draw[gray!15, line width=0.15pt] (\x,0) -- (\x,\ch); }
    \foreach \y in {0,10,...,70} { \draw[gray!15, line width=0.15pt] (0,\y) -- (\cw,\y); }
  \end{scope}
  \draw[black, line width=0.5pt, rounded corners=1.8mm] (0,0) rectangle (\cw,\ch);
  \fill[gray!20, rounded corners=0.9mm] (20,-6) rectangle (40,0);
  \fill[gray!20, rounded corners=0.9mm] (\cw-40,-6) rectangle (\cw-20,0);

  % VU L: 60x40mm landscape
  \draw[gray!45, line width=0.4pt, dashed] (10,15) rectangle (70,55);
  \node[font=\fontsize{6}{8}\selectfont, text=gray!50] at (40,37) {VU L};
  \node[font=\fontsize{4}{5}\selectfont, text=gray!35] at (40,27) {60x40};

  % VU R: 60x40mm landscape
  \draw[gray!45, line width=0.4pt, dashed] (365,15) rectangle (425,55);
  \node[font=\fontsize{6}{8}\selectfont, text=gray!50] at (395,37) {VU R};
  \node[font=\fontsize{4}{5}\selectfont, text=gray!35] at (395,27) {60x40};

  % 5" Display centred
  \draw[black!55, line width=0.5pt, dashed] (162,4) rectangle (273,66);
  \node[font=\fontsize{7}{9}\selectfont, text=gray!45] at (217.5,39) {5" Display};
  \node[font=\fontsize{5}{7}\selectfont, text=gray!35] at (217.5,28) {111 x 62mm};
  \draw[gray!12, line width=0.2pt, dashed] (217.5,4) -- (217.5,66);
  \draw[gray!12, line width=0.2pt, dashed] (162,35) -- (273,35);

  % Rotary
  \draw[gray!40, line width=0.3pt, dashed] (425,35) circle (8);
  \node[font=\fontsize{4}{5}\selectfont, text=gray!40] at (425,35) {VOL};

  % Dims
  \draw[gray!35, line width=0.2pt, <->] (0,\ch+4) -- (\cw,\ch+4);
  \node[font=\fontsize{5}{7}\selectfont, text=gray!40] at (\cw/2,\ch+8) {435mm};
  \draw[gray!35, line width=0.2pt, <->] (\cw+4,0) -- (\cw+4,\ch);
  \node[font=\fontsize{5}{7}\selectfont, text=gray!40, rotate=90] at (\cw+8,\ch/2) {70mm};
\end{tikzpicture}
\end{center}

\vspace{4mm}

%% ============================================================
%% OPTION D: Rectangular VU 50x60mm (portrait) + 5" display + buttons + rotary
%% ============================================================

\noindent
{\fontsize{9}{11}\selectfont\bfseries D: 50x60mm rectangular VU (portrait) + 5" display + 4 buttons + rotary}

\vspace{1mm}

\begin{center}
\begin{tikzpicture}[x=0.92mm, y=0.92mm]
  \def\cw{435} \def\ch{70}

  \begin{scope}
    \clip[rounded corners=1.8mm] (0,0) rectangle (\cw,\ch);
    \foreach \x in {0,10,...,435} { \draw[gray!15, line width=0.15pt] (\x,0) -- (\x,\ch); }
    \foreach \y in {0,10,...,70} { \draw[gray!15, line width=0.15pt] (0,\y) -- (\cw,\y); }
  \end{scope}
  \draw[black, line width=0.5pt, rounded corners=1.8mm] (0,0) rectangle (\cw,\ch);
  \fill[gray!20, rounded corners=0.9mm] (20,-6) rectangle (40,0);
  \fill[gray!20, rounded corners=0.9mm] (\cw-40,-6) rectangle (\cw-20,0);

  % VU L: 50x60mm portrait
  \draw[gray!45, line width=0.4pt, dashed] (15,5) rectangle (65,65);
  \node[font=\fontsize{6}{8}\selectfont, text=gray!50] at (40,38) {VU L};
  \node[font=\fontsize{4}{5}\selectfont, text=gray!35] at (40,27) {50x60};

  % 5" Display
  \draw[black!55, line width=0.5pt, dashed] (95,4) rectangle (206,66);
  \node[font=\fontsize{7}{9}\selectfont, text=gray!45] at (150.5,39) {5" Display};
  \node[font=\fontsize{5}{7}\selectfont, text=gray!35] at (150.5,28) {111 x 62mm};
  \draw[gray!12, line width=0.2pt, dashed] (150.5,4) -- (150.5,66);
  \draw[gray!12, line width=0.2pt, dashed] (95,35) -- (206,35);

  % VU R: 50x60mm portrait
  \draw[gray!45, line width=0.4pt, dashed] (230,5) rectangle (280,65);
  \node[font=\fontsize{6}{8}\selectfont, text=gray!50] at (255,38) {VU R};
  \node[font=\fontsize{4}{5}\selectfont, text=gray!35] at (255,27) {50x60};

  % Buttons
  \foreach \i/\lbl in {1/BBC,2/TDL,3/PLX,4/RDO} {
    \pgfmathsetmacro{\bty}{70 - \i * 15 - 2}
    \draw[gray!40, line width=0.3pt, dashed] (340,\bty) circle (5);
    \node[font=\fontsize{3.5}{4}\selectfont, text=gray!40] at (340,\bty) {\lbl};
  }
  % Rotary
  \draw[gray!40, line width=0.3pt, dashed] (400,35) circle (8);
  \node[font=\fontsize{4}{5}\selectfont, text=gray!40] at (400,35) {VOL};

  % Dims
  \draw[gray!35, line width=0.2pt, <->] (0,\ch+4) -- (\cw,\ch+4);
  \node[font=\fontsize{5}{7}\selectfont, text=gray!40] at (\cw/2,\ch+8) {435mm};
  \draw[gray!35, line width=0.2pt, <->] (\cw+4,0) -- (\cw+4,\ch);
  \node[font=\fontsize{5}{7}\selectfont, text=gray!40, rotate=90] at (\cw+8,\ch/2) {70mm};
\end{tikzpicture}
\end{center}

\vspace{3mm}

\begin{center}
{\fontsize{7}{9}\selectfont\color{gray}
\begin{tabular}{lcccc}
& \textbf{Case} & \textbf{Display} & \textbf{Physical VU} & \textbf{Controls} \\[2pt]
\textbf{A} & 435 $\times$ 70mm & 5" (111 $\times$ 62) & 2 $\times$ 45mm circular & 4 buttons + rotary \\
\textbf{B} & 435 $\times$ 70mm & 5" (111 $\times$ 62) & 2 $\times$ 50mm circular & rotary only \\
\textbf{C} & 435 $\times$ 70mm & 5" (111 $\times$ 62) & 2 $\times$ 60x40 rectangular & rotary only \\
\textbf{D} & 435 $\times$ 70mm & 5" (111 $\times$ 62) & 2 $\times$ 50x60 rect portrait & 4 buttons + rotary \\[3pt]
\hline \\[-6pt]
\multicolumn{5}{l}{\textit{Drawn at 92\% scale. NAD C 368: 435 $\times$ 102mm | NAD C 338: 435 $\times$ 70mm}}
\end{tabular}}
\end{center}

\end{document}

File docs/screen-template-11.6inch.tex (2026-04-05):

\documentclass{article}
\usepackage[a3paper,landscape,margin=15mm]{geometry}
\usepackage{tikz}
\usepackage{fontspec}
\setmainfont{Inter}
\pagestyle{empty}

\begin{document}
\noindent
\begin{center}
{\fontsize{16}{20}\selectfont\bfseries TheStreamDeck --- 11.6\textquotedbl{} Display Template (1920\texttimes1080, 16:9)}\\[4pt]
{\fontsize{10}{14}\selectfont\color{gray} Print at 100\% on A3 paper --- actual size for sketching}
\end{center}

\vfill

\begin{center}
\begin{tikzpicture}
  % Screen: 256.8mm x 144.5mm (11.6" 16:9)
  \def\sw{25.68}  % screen width in cm
  \def\sh{14.45}  % screen height in cm

  % Grid (1cm spacing) - light grey
  \begin{scope}
    \clip (0,0) rectangle (\sw,\sh);
    \foreach \x in {0,1,...,25} {
      \draw[gray!20, line width=0.3pt] (\x,0) -- (\x,\sh);
    }
    \foreach \y in {0,1,...,14} {
      \draw[gray!20, line width=0.3pt] (0,\y) -- (\sw,\y);
    }
  \end{scope}

  % Screen border
  \draw[black, line width=1pt] (0,0) rectangle (\sw,\sh);

  % Pixel dimension labels
  \node[anchor=south west, font=\fontsize{8}{10}\selectfont, text=gray!50] at (0.2,\sh-0.5) {1920px};
  \node[anchor=south west, font=\fontsize{8}{10}\selectfont, text=gray!50, rotate=90] at (\sw-0.5,0.2) {1080px};

  % Centre crosshair (subtle)
  \draw[gray!15, line width=0.5pt, dashed] (\sw/2,0) -- (\sw/2,\sh);
  \draw[gray!15, line width=0.5pt, dashed] (0,\sh/2) -- (\sw,\sh/2);

  % Physical dimension arrows
  \draw[gray!40, line width=0.4pt, <->] (0,-0.8) -- (\sw,-0.8) node[midway, below, font=\fontsize{7}{9}\selectfont, text=gray!50] {256.8mm (10.11\textquotedbl)};
  \draw[gray!40, line width=0.4pt, <->] (-0.6,0) -- (-0.6,\sh) node[midway, left, font=\fontsize{7}{9}\selectfont, text=gray!50, rotate=90, anchor=south] {144.5mm (5.69\textquotedbl)};

\end{tikzpicture}
\end{center}

\vspace{2mm}
\begin{center}
{\fontsize{9}{12}\selectfont\color{gray} Waveshare 11.6\textquotedbl{} HDMI LCD (H) --- 1920\texttimes1080 IPS}
\end{center}

\vfill

\end{document}

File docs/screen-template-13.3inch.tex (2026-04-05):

\documentclass{article}
\usepackage[a3paper,landscape,margin=15mm]{geometry}
\usepackage{tikz}
\usepackage{fontspec}
\setmainfont{Inter}
\pagestyle{empty}

\begin{document}
\noindent
\begin{center}
{\fontsize{16}{20}\selectfont\bfseries TheStreamDeck --- 13.3\textquotedbl{} Display Template (1920\texttimes1080, 16:9)}\\[4pt]
{\fontsize{10}{14}\selectfont\color{gray} Print at 100\% on A3 paper --- actual size for sketching}
\end{center}

\vfill

\begin{center}
\begin{tikzpicture}
  % Screen: 294.4mm x 165.6mm (13.3" 16:9)
  \def\sw{29.44}  % screen width in cm
  \def\sh{16.56}  % screen height in cm

  % Grid (1cm spacing) - light grey
  \begin{scope}
    \clip (0,0) rectangle (\sw,\sh);
    \foreach \x in {0,1,...,29} {
      \draw[gray!20, line width=0.3pt] (\x,0) -- (\x,\sh);
    }
    \foreach \y in {0,1,...,16} {
      \draw[gray!20, line width=0.3pt] (0,\y) -- (\sw,\y);
    }
  \end{scope}

  % Screen border
  \draw[black, line width=1pt] (0,0) rectangle (\sw,\sh);

  % Pixel dimension labels
  \node[anchor=south west, font=\fontsize{8}{10}\selectfont, text=gray!50] at (0.2,\sh-0.5) {1920px};
  \node[anchor=south west, font=\fontsize{8}{10}\selectfont, text=gray!50, rotate=90] at (\sw-0.5,0.2) {1080px};

  % Centre crosshair (subtle)
  \draw[gray!15, line width=0.5pt, dashed] (\sw/2,0) -- (\sw/2,\sh);
  \draw[gray!15, line width=0.5pt, dashed] (0,\sh/2) -- (\sw,\sh/2);

  % Physical dimension arrows
  \draw[gray!40, line width=0.4pt, <->] (0,-0.8) -- (\sw,-0.8) node[midway, below, font=\fontsize{7}{9}\selectfont, text=gray!50] {294.4mm (11.59\textquotedbl)};
  \draw[gray!40, line width=0.4pt, <->] (-0.6,0) -- (-0.6,\sh) node[midway, left, font=\fontsize{7}{9}\selectfont, text=gray!50, rotate=90, anchor=south] {165.6mm (6.52\textquotedbl)};

\end{tikzpicture}
\end{center}

\vspace{2mm}
\begin{center}
{\fontsize{9}{12}\selectfont\color{gray} Waveshare 13.3\textquotedbl{} HDMI LCD (H) V2 --- 1920\texttimes1080 IPS}
\end{center}

\vfill

\end{document}

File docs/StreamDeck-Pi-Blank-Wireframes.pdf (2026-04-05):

## TheStreamDeck – Blank Wireframe 70mm

92% scale on A3 (actual: 435 x 70mm). Clean real estate for free sketching.

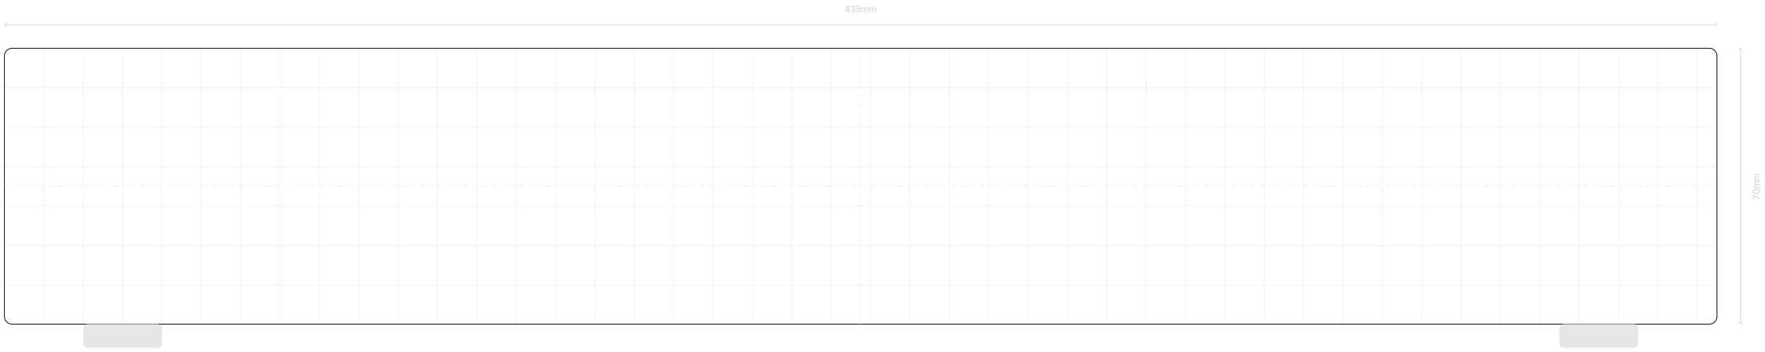
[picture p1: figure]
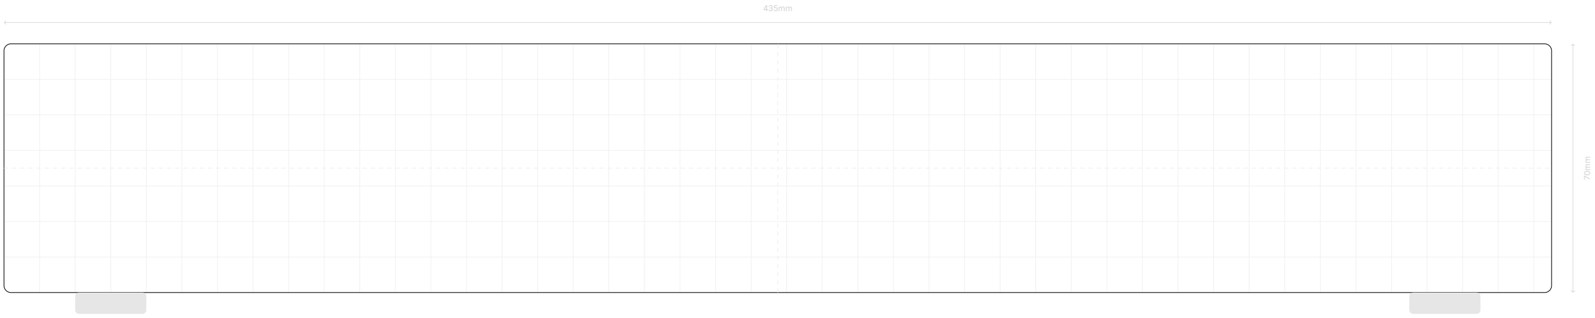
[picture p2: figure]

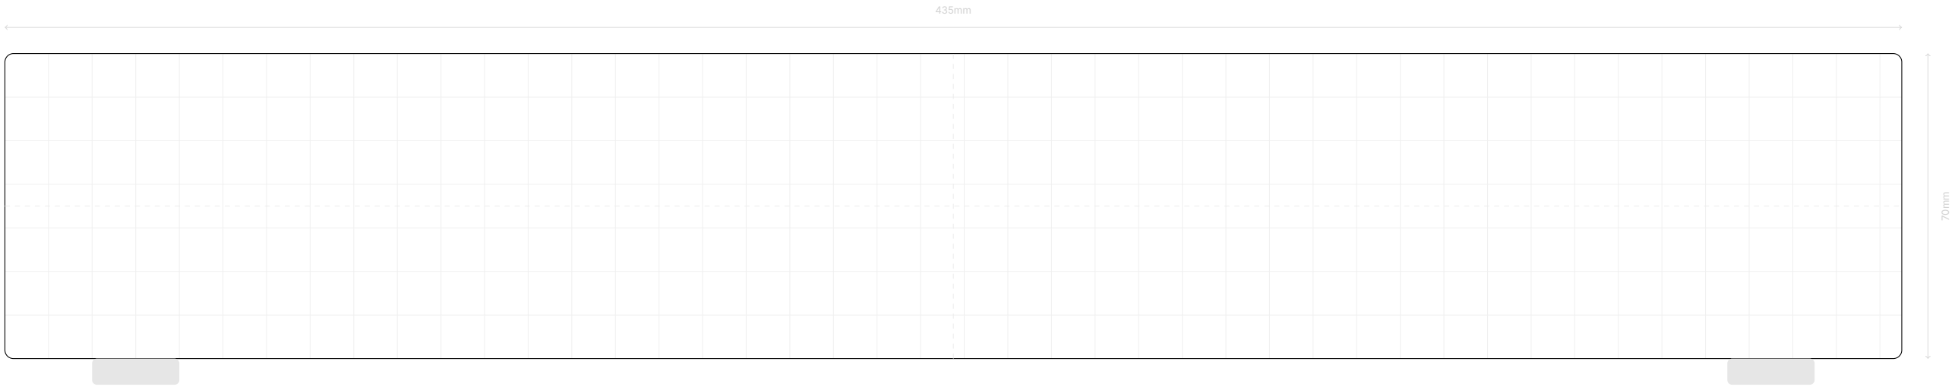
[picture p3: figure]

## TheStreamDeck – Blank Wireframe 102mm

92% scale on A3 (actual: 435 x 102mm). Clean real estate for free sketching.

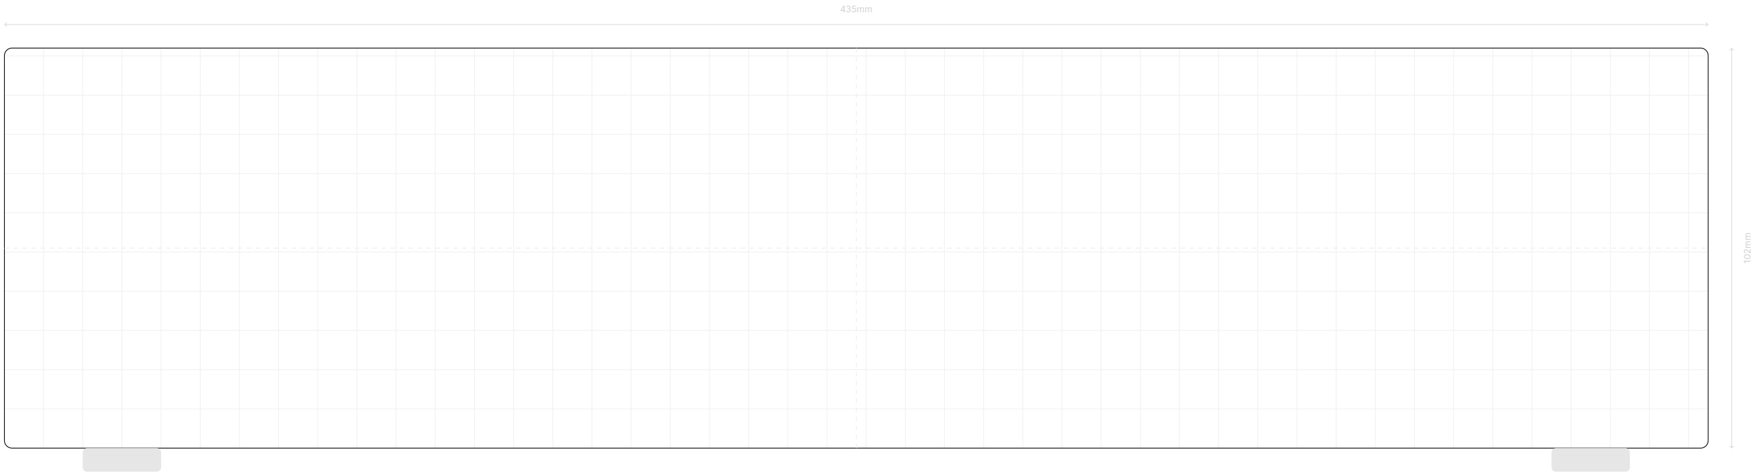
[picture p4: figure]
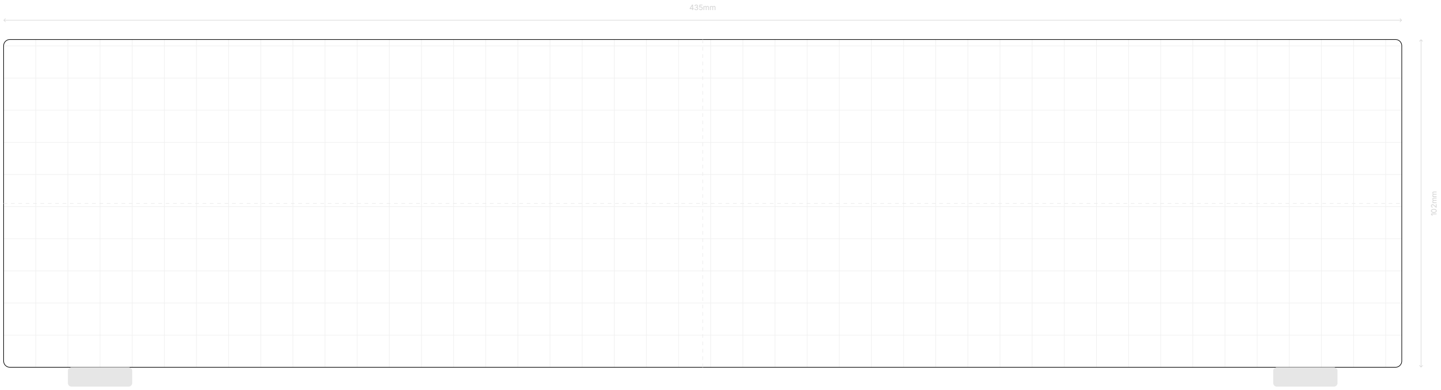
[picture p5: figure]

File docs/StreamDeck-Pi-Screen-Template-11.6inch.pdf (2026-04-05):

StreamDeck Pi — 11.6" Display Template 19201080, 169

Print at 100% on A3 paper — actual size for sketching

1920px

1080px

256.8mm 10.11")

144.5mm 5.69")

Waveshare 11.6" HDMI LCD H — 19201080 IPS

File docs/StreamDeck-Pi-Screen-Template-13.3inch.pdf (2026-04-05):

StreamDeck Pi — 13.3" Display Template 19201080, 169

Print at 100% on A3 paper — actual size for sketching

1920px

1080px

294.4mm 11.59")

165.6mm 6.52")

Waveshare 13.3" HDMI LCD H V2 — 19201080 IPS

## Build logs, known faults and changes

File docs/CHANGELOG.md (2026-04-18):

# Changelog

All notable changes to TheStreamDeck project.

## [0.4.0] - 2026-04-12

### Added
- Bandcamp as a streaming source (discovery/browse only — purchased FLACs remain in Plexamp path)
- NTS Radio (ntslive.co.uk) — two 24/7 live channels, web player or MPD fallback
- Worldwide.fm — curated DJ-driven internet radio, web player or MPD fallback
- §3.7 Network Layer: BBC VPN split-tunnel via Mullvad WireGuard with automatic UK-endpoint rotation on failure
- Tiered Tidal client strategy: SONE (Tauri 2/Rust, best stack fit) → tidalt (confirmed ARM64) → custom Rust client → play.tidal.com (lossy last resort)
- Source category table in §3.3 (native backend / standalone app / web-native / Chromium escalation)
- Mullvad VPN subscription added to BOM (€5/month)
- 5 new risk entries (Tidal API breakage, SONE ARM64 viability, WebKitGTK source compat, VPN rotation exhaustion, panel space for 5th button)

### Changed
- **UI architecture: Slint → Tauri 2 (Rust + WebKitGTK)** — native Rust backend for GPIO/PipeWire/SPI, WebKitGTK webview hosts per-source web UIs. Chromium available as per-source escalation fallback.
- Tidal control model: cast-from-phone (GioF71/tidal-connect) → 100% on-device control via dedicated Linux client (SONE/tidalt/custom). Lossless FLAC preserved.
- Plexamp control model: cast-only → primary control from StreamDeck touchscreen via localhost:32500 in Tauri webview. Cast-from-phone remains as bonus.
- Source switching architecture diagram updated for 7 sources + Tauri shell ownership
- VU meter on-screen pipeline: Slint widget → Tauri IPC + Canvas/WebGL in webview (physical MCP4922 path unchanged)
- Build phases restructured: Phase 2 now covers VPN + additional sources, Phase 3 covers Tauri shell + display
- GPIO button table: added Bandcamp (GPIO 25), renumbered Radio to button 5, Play/Pause to 6, Volume to 7
- UI Technology Options table: added Option E (Tauri 2), marked as selected. Slint (Option B) rejected — no native webview for per-source UIs.
- Risks table: replaced stale Tidal Connect and Slint risks with Tauri/WebKitGTK, VPN, and new-source-specific risks

## [0.3.1] - 2026-04-05

### Changed
- Project renamed from "StreamDeck Pi" to "TheStreamDeck"
- All references updated across specs, diagrams, KiCad schematic, and LaTeX sources

## [0.3.0] - 2026-04-05

### Added
- Front panel layout concept diagram (STREAMDECK-CONC-001 Rev A) — 5" display centred, source buttons flanking, available zones for VU meters
- Blank wireframe PDFs for free sketching — 70mm (x3) and 102mm (x2) form factors at 92% scale on A3
- Case wireframe PDFs with four layout options (circular + rectangular VU meters) at 70mm height

### Changed
- Display decision revised: 13.3" and 10.1" too tall for NAD-matching form factor. 5" (111 x 62mm) is the max that fits 70mm case height.
- Form factor locked to 435mm width (NAD C 3xx standard). Max height 70mm (NAD C 338 profile).
- VU meter sizing revised: 45-50mm circular or 60x40mm rectangular at 70mm case height. 85mm meters no longer viable.

## [0.2.0] - 2026-04-05

### Added
- Analogue VU meter subsystem — MCP4922 dual SPI DAC driving two 85mm panel meters (L/R)
- VU meter driver KiCad schematic (`code/streamdeck-vu-driver.kicad_sch`)
- ElectricalEngineer skill created for KiCad schematic production
- Electrical engineering language reference (IEC 61082, IEC 60617, IEC 81346, ISO 5457, ISO 7200, ISO 128)
- Printable actual-size screen templates (13.3" and 11.6") as A3 PDFs for UI sketching
- Architecture diagram Rev B with MCP4922 + VU meters + updated display

### Changed
- Display upgraded from 7" Pi Touch Display 2 (DSI, 720p) to Waveshare 13.3" HDMI LCD (H) V2 (1080p)
- UI layout updated from 1280x720 to 1920x1080 — album art area enlarged to 600x600px
- GPIO allocation updated: SPI0 (GPIO 8/10/11) added for DAC, DSI pins freed
- Performance budget updated for 1080p rendering (~9-16% CPU)
- BOM updated: $255-290 → $275-335 (display + VU meter components)

## [0.1.0] - 2026-04-04

### Added
- Project initialised with problem statement and technical specification
- Hardware architecture: Pi 4B + HiFiBerry Digi2 Pro (S/PDIF) + NAD C 3xx optical input
- First-principles analysis: Digi HAT over DAC HAT — Pi stays purely digital
- Software stack: Pi OS Lite 64-bit, PipeWire, MPD, tidal-connect (Podman), Plexamp headless
- Source switching architecture with Rust daemon + Slint UI
- VU meter visualisation pipeline: cpal + RustFFT (NEON) at 60fps
- Architecture diagram Rev A (STREAMDECK-ARCH-001)
- 758-line research file covering all integration approaches
- 5-phase build plan with weekly milestones

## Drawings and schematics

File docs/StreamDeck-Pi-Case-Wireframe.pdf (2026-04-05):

# TheStreamDeck – Front Panel Wireframes 70mm height)

92% scale on A3 (actual case is 435 x 70mm). Multiply measurements by 1.087 for true dimensions.

### A 45mm circular VU + 5” display + 4 buttons + rotary

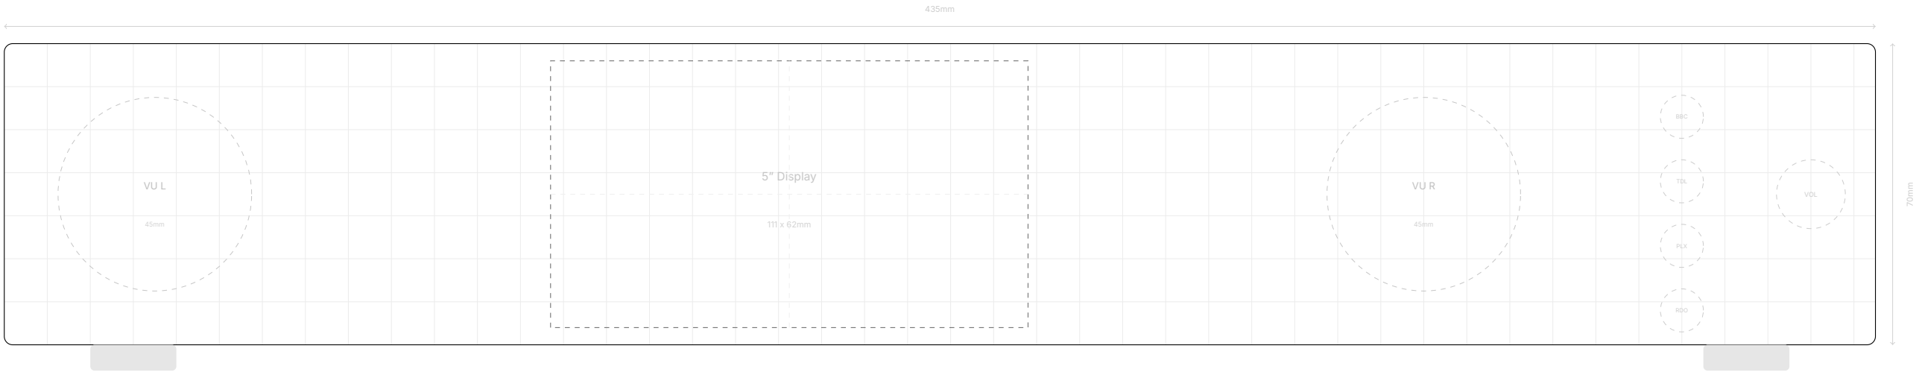
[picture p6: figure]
5” Display; BBC; TDL; PLX; RDO; VOL

### B 50mm circular VU + 5” display + rotary only

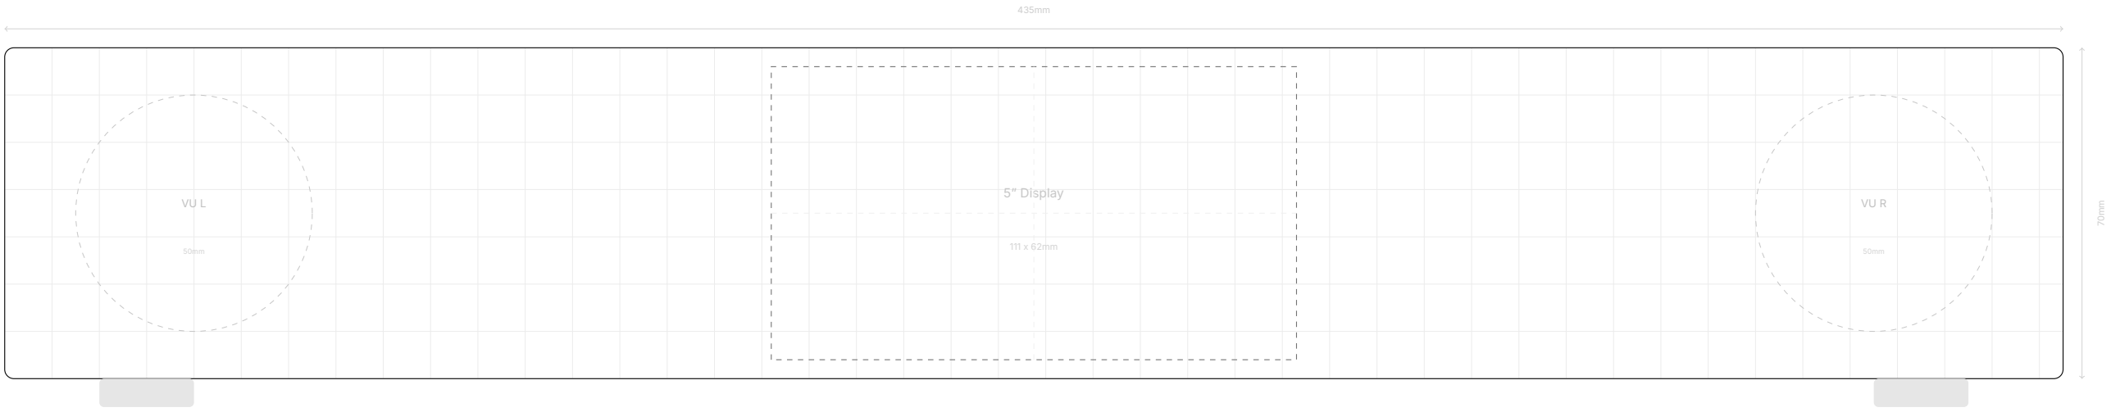
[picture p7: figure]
5” Display

### C 60x40mm rectangular VU (landscape) + 5” display + rotary

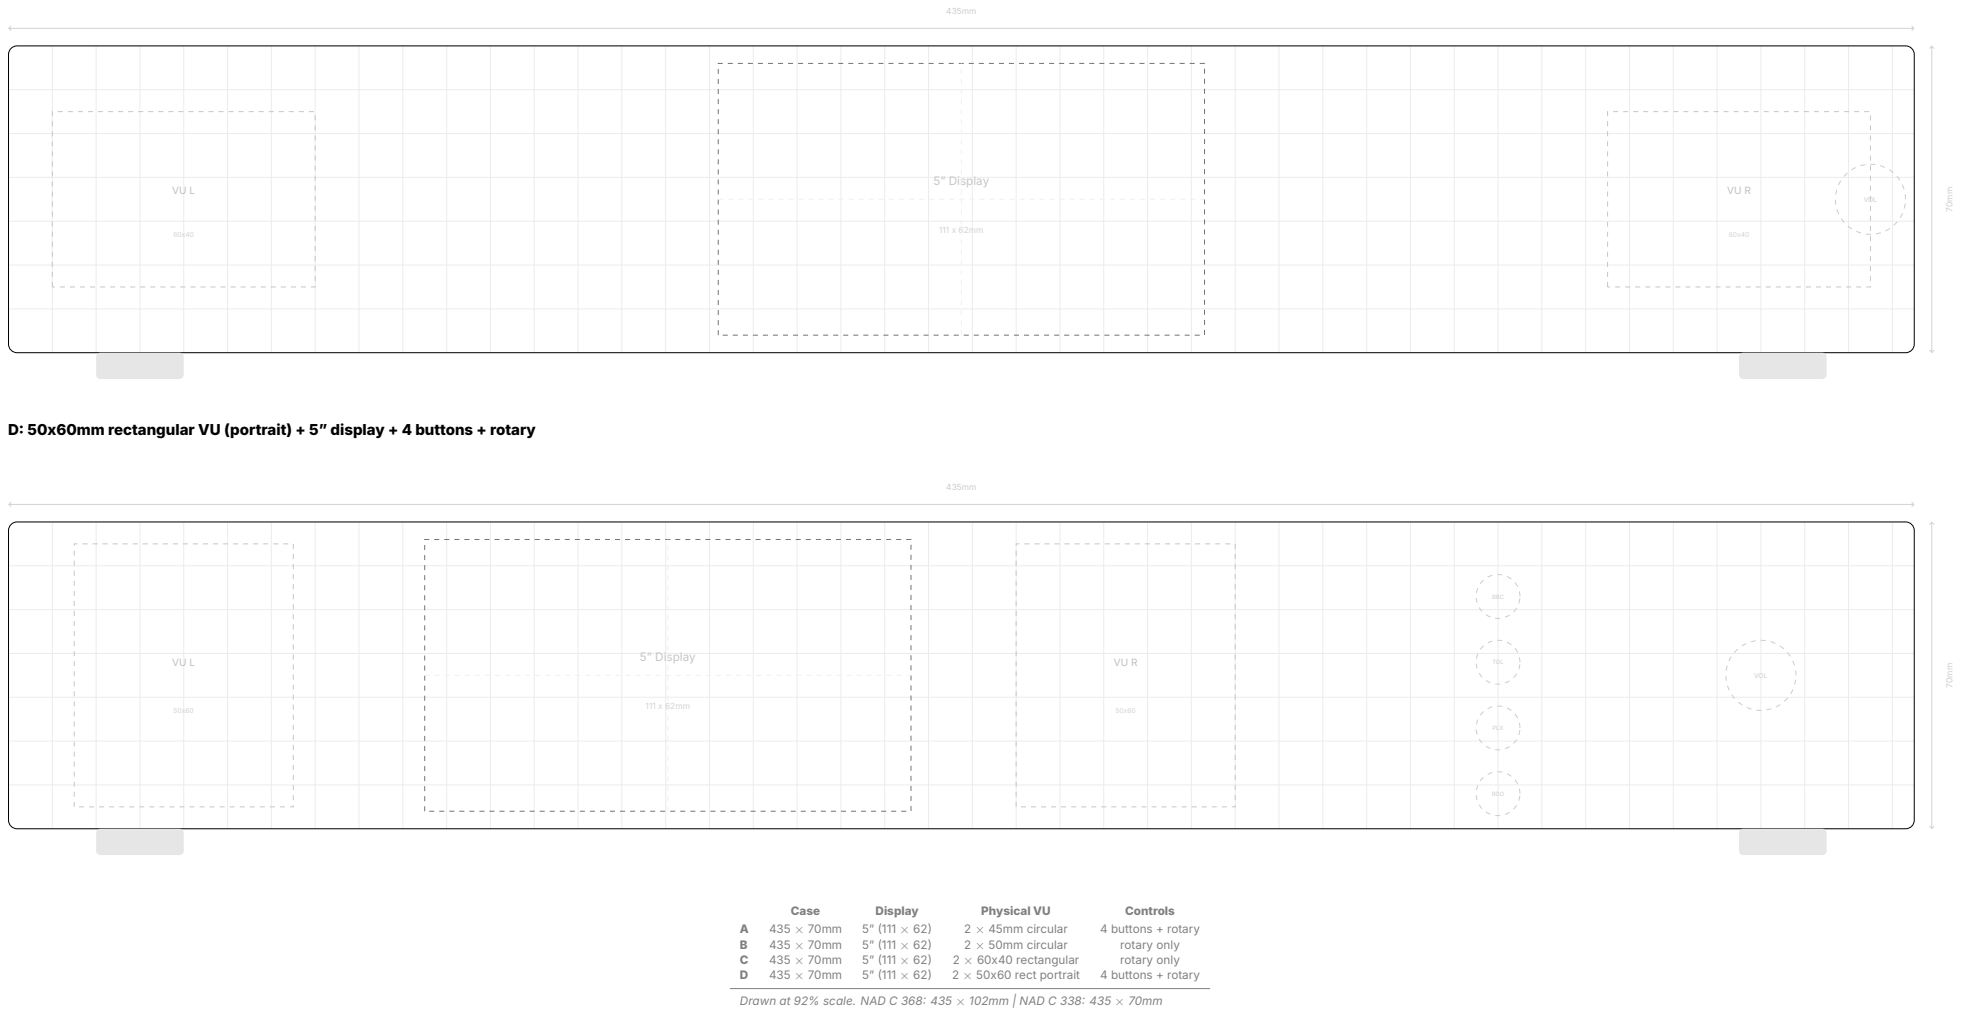
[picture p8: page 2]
5” Display; VOL; BBC; TDL; PLX; RDO; Case; Display; Physical VU; Controls; 2 × 45mm circular; 4 buttons + rotary; 2 × 50mm circular; rotary only; 2 × 60x40 rectangular; 2 × 50x60 rect portrait

D 50x60mm rectangular VU (portrait) + 5” display + 4 buttons + rotary

Drawn at 92% scale. NAD C 368 435 × 102mm | NAD C 338 435 × 70mm

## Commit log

2026-04-05 StreamDeck Pi v0.2.0 — design spec, VU meter driver, architecture diagrams
    Unified Raspberry Pi 4 streaming audio appliance consolidating BBC 6 Music,
    Tidal HiFi Plus, Plexamp, and internet radio into a single device with 13.3"
    touchscreen, physical VU meters, and S/PDIF digital output to NAD C 3xx amp.
    Includes: problem statement, full technical spec (v0.2.0), architecture
    diagrams (Rev A + B), MCP4922 VU meter driver KiCad schematic, printable
    screen templates for UI sketching, and changelog.
    [streamdeck-vu-driver.kicad_sch]
2026-04-05 v0.3.0 — front panel concept, blank wireframes, form factor locked to 70mm
    Display revised from 13.3" to 5" (111x62mm) to fit 70mm NAD-matching case
    height. Front panel concept diagram (CONC-001) with centred display, source
    buttons flanking, and available zones for VU meters. Blank wireframe PDFs
    for both 70mm and 102mm form factors for free sketching.
2026-04-05 v0.3.1 — rename project to TheStreamDeck
    Renamed from "StreamDeck Pi" to "TheStreamDeck". Directory moved from
    PROJECTS/private/streaming-appliance/ to PROJECTS/public/TheStreamDeck/.
    All references updated across specs, diagrams, KiCad schematic, LaTeX
    sources, and PAI memory index.
    [streamdeck-vu-driver.kicad_sch]
2026-04-05 Add NAD-style low-profile feet to all wireframes and concept diagram
    Replaced placeholder circle feet with NAD-style rounded rectangular feet
    (20mm wide x 6mm tall, 20mm inset from sides) across draw.io concept
    diagram and all PDF wireframes (blank + case options). Matches NAD C 3xx
    foot proportions.
2026-04-18 Ignore code/ directory — not yet written
2026-04-18 Remove code/ from tracking — not yet ready
    [streamdeck-vu-driver.kicad_sch]
